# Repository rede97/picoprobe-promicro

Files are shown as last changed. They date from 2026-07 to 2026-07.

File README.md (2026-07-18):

# picoprobe-promicro

[中文版本](README_CN.md)

---

A Raspberry Pi Debug Probe expansion board based on the **RP2040 Pro Micro** core module. The circuit is fully compatible with the [official Raspberry Pi Debug Probe](https://www.raspberrypi.com/products/debug-probe/) — simply plug a RP2040 Pro Micro onto this board, flash the **official Debug Probe firmware from Raspberry Pi**, and you're ready to go. No custom firmware needed.

The RP2040 Pro Micro has onboard **Boot** and **Reset** buttons, making firmware flashing effortless: hold Boot → press Reset → release Boot, and a USB mass storage drive appears — just drag and drop the `.uf2` firmware file. No jumper wires or complicated steps required.

## Compatibility & Reliability

What's truly surprising is how well the Raspberry Pi Debug Probe works beyond its intended target. Its compatibility and reliability are **far beyond expectations**. It not only handles RP2040 chips perfectly, but also delivers rock-solid debugging and flashing for a wide range of **ARM microcontrollers and SoCs** — the full STM32 lineup, Nordic chips like the nRF52840, and virtually any Cortex-M core MCU.

Thanks to the RP2040's **PIO hardware**, the Debug Probe achieves exceptionally fast SWD transfer speeds, matching or exceeding some USB high-speed debuggers in practice. Over long debugging sessions across various target chips, it shows none of the common issues — no disconnections, no timeouts, no failed device recognition.

## Motivation

The official Raspberry Pi Debug Probe has a few shortcomings:

- It still uses a **Micro USB** connector, while USB-C has become the standard
- Flashing Picoprobe firmware onto a bare Pico often leads to **various stability issues**
- Designing a complete dedicated debugger PCB is overkill for many users
- It's essentially just an RP2040 + level-shifting circuit — the official price is steep for a fixed-function debug board

Meanwhile, open-source DAPLink solutions generally have **worse compatibility and stability** across ARM chips compared to the Raspberry Pi Debug Probe.

## Fully Open Source

This is one of the project's biggest strengths:

- **Fully open hardware**: All PCB design files (schematic, layout) are open source in KiCad format. Anyone can inspect, modify, or order their own boards
- **Firmware is fully open source**: Uses the official Raspberry Pi [debugprobe firmware](https://github.com/raspberrypi/debugprobe) directly — no proprietary or custom code. Maintained by Raspberry Pi, continuously updated, with guaranteed quality
- **No closed-source burden**: Many DAPLink debuggers on the market ship with proprietary firmware. When bugs appear, there's no one to report to and no way to upgrade or fix yourself. This solution is open source from hardware to firmware — community-driven and never obsolete

## Regarding JTAG

This project currently supports **SWD** only, not JTAG. From a practical standpoint:

- The vast majority of Cortex-M MCU debugging and flashing only requires SWD — JTAG is not necessary
- If you genuinely need JTAG along with Trace, ETM, and other advanced debugging features, a mature **J-Link** is the better choice — at that point you need a complete professional debugging toolchain, not just a protocol interface

Future firmware-level JTAG support is not out of the question (the RP2040's PIO is capable in hardware), but there are no concrete plans at this stage.

## Design Approach

Rather than designing a complete debugger from scratch, this project pairs a widely available **RP2040 Pro Micro** module with a dedicated expansion board:

- **Flexible**: Use pin headers and female header sockets to temporarily mount the Pro Micro on the board for debugging — detach and reuse it anytime
- **Permanent option**: Solder short pin headers to permanently join the Pro Micro and the board together as a dedicated, long-term debug probe
- **Ultra-low BOM cost**: Significantly cheaper than the official Debug Probe
- **Zero pressure**: No worries about damaging an expensive debugger — hack, modify, or build your own features on top

## PCB Renders

| Front | Back |
|:---:|:---:|
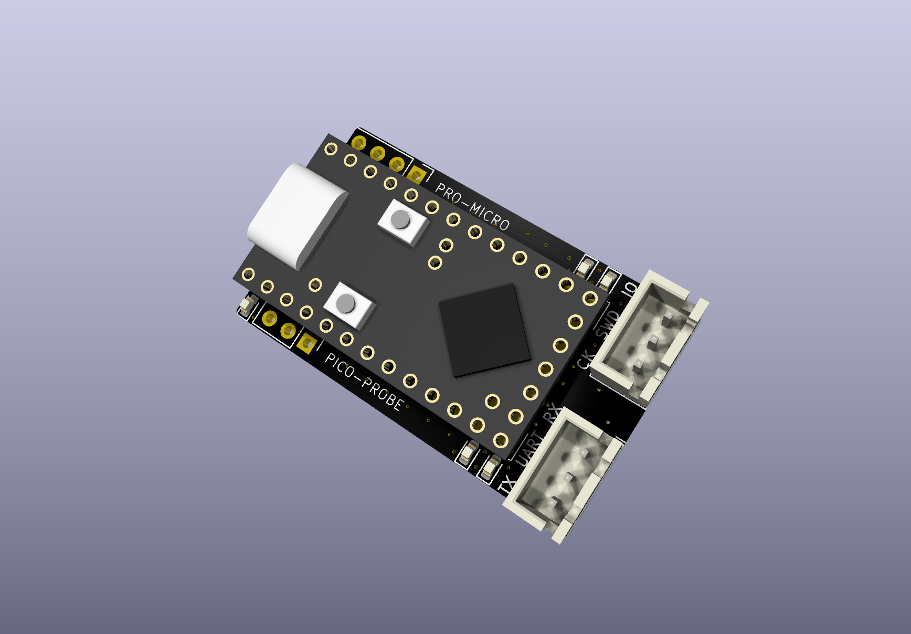
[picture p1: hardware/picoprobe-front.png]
Front
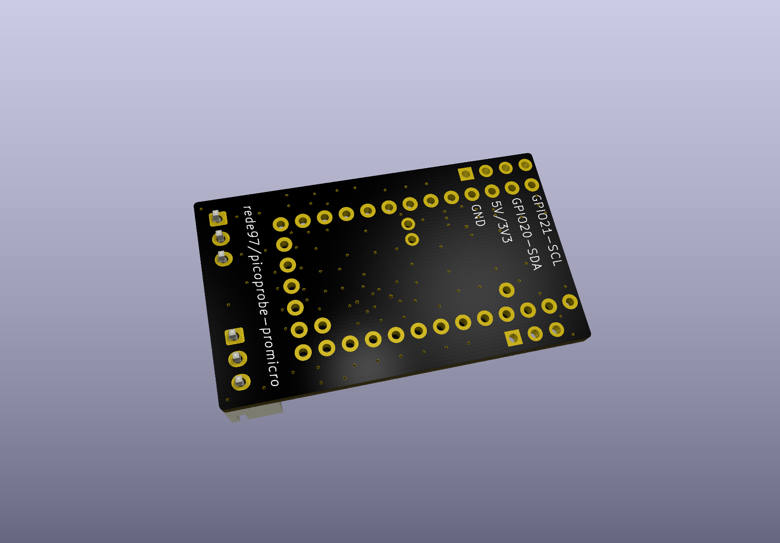
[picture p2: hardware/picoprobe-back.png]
Back
|  |  |

[Download schematic PDF](hardware/picoprobe_sch.pdf)

## Real-World Photos

This debugger works perfectly with both the **Raspberry Pi Pico 2** and the **nRF52840** — rock-solid in practice, with very fast download speeds.

### 1. Detachable socket assembly

The Pro Micro is mounted on the board via pin headers and female header sockets. Plug it in to debug; pull it off anytime and reuse the module in other projects.

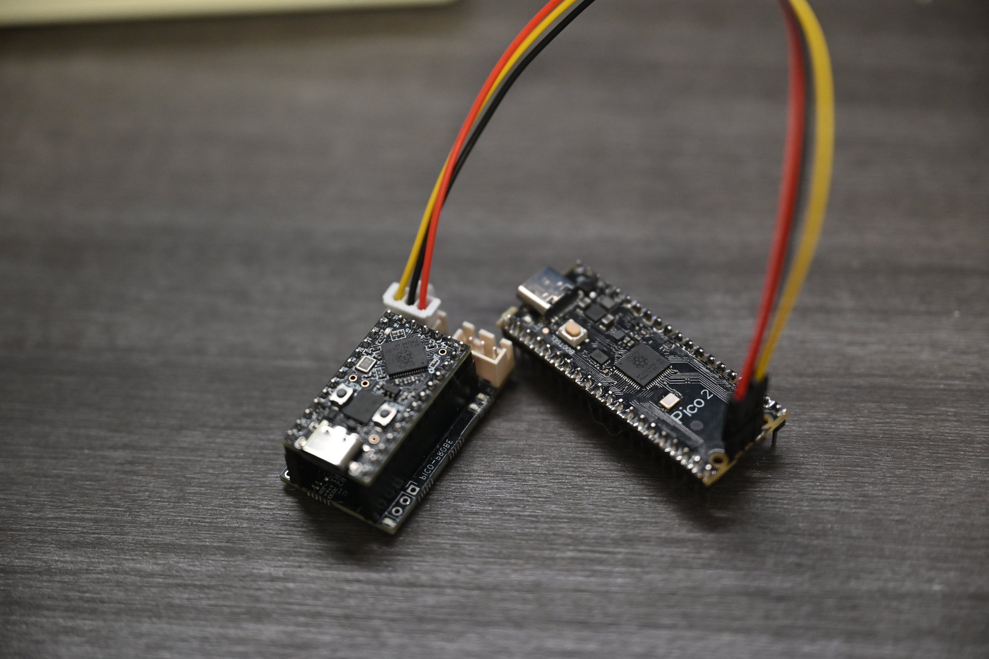
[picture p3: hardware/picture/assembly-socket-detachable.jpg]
Detachable socket assembly


### 2. Soldered as one piece

The Pro Micro is soldered directly onto the board as a single, integrated unit. This version is smaller in volume, and is otherwise **functionally identical** to the detachable version — same circuit, same performance.

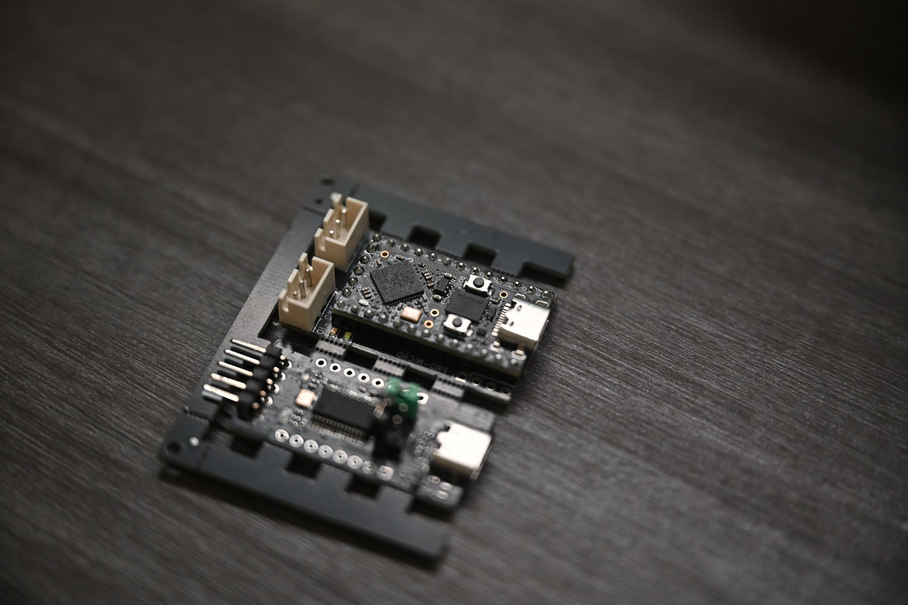
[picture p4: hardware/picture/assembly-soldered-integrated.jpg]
Soldered as one piece


### 3. Debugging an nRF52840

Debugging and flashing an nRF52840 target over SWD. Works flawlessly, with very fast download speeds.

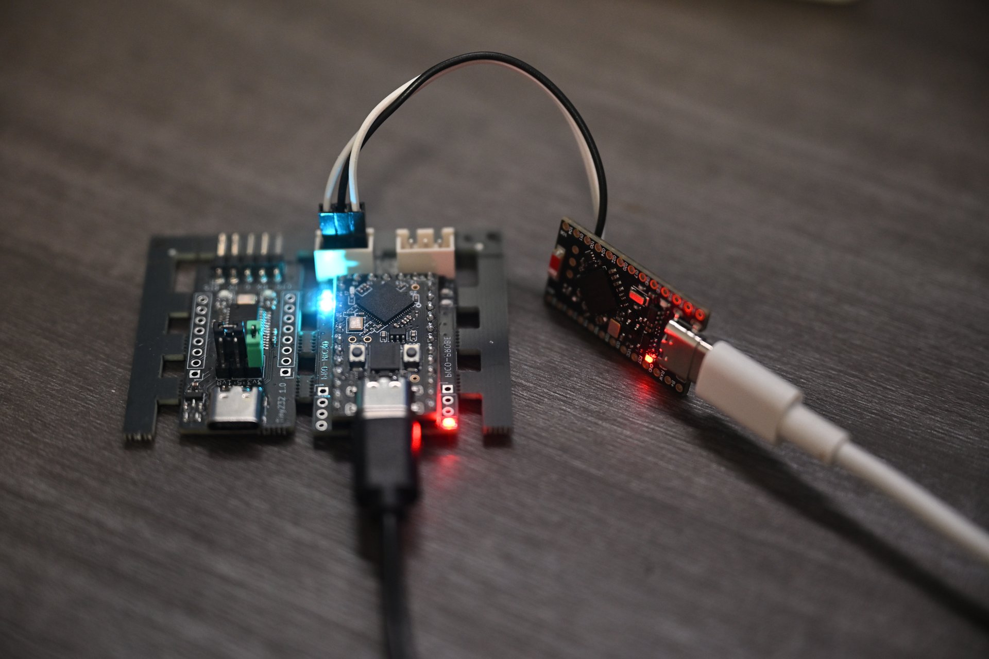
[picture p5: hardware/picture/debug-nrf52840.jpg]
Debugging an nRF52840


## Project Structure

```
├── hardware/
│   ├── picoprobe.kicad_sch      # Schematic
│   ├── picoprobe.kicad_pcb      # PCB layout
│   ├── picoprobe.kicad_pro      # KiCad project file
│   ├── picoprobe-front.png      # Front render
│   ├── picoprobe-back.png       # Back render
│   ├── picoprobe_sch.pdf        # Schematic PDF
│   ├── picture/                 # Real-world photos
│   └── kicad_pro_micro_rp2040/  # Pro Micro RP2040 footprint library (submodule)
├── README.md
└── README_CN.md
```

## Dependencies

- [kicad_pro_micro_rp2040](https://github.com/rroels/kicad_pro_micro_rp2040) — KiCad symbol and footprint library for the Pro Micro RP2040

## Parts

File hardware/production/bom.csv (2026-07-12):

Designator | Footprint | Quantity | Value | LCSC Part #
C1, C2 | 0402 | 2 | 4.7u | C23733
C3, C4 | 0402 | 2 | 0.1u | C307331
D1 | 0603 | 1 | RED LED | C2286
D2, D4 | 0603 | 2 | GREEN LED | C7496818
D3, D5 | 0603 | 2 | YELLOW LED | C965800
J1 | PinHeader_1x04_P2.54mm_Vertical | 1 | Conn_01x04_Pin
J2 | PinHeader_1x03_P2.54mm_Vertical | 1 | Conn_01x03_Pin
J3, J4 | JST_XH_B3B-XH-A_1x03_P2.50mm_Vertical | 2 | Conn_01x03_Pin
R1, R10, R9 | 0402 | 3 | 0R(NC) | C17168
R11, R12, R5, R6, R7, R8 | 0402 | 6 | 100R | C25076
R13, R14, R15, R16, R3 | 0402 | 5 | 470R | C25117
R17, R18, R19 | 0402 | 3 | 4.7k | C25900
R2 | 0402 | 1 | 0R | C17168
U1 | pro_micro_rp2040 | 1 | ~
U2, U3 | SOT-23-5 | 2 | 74AUP1G17 | C48946883

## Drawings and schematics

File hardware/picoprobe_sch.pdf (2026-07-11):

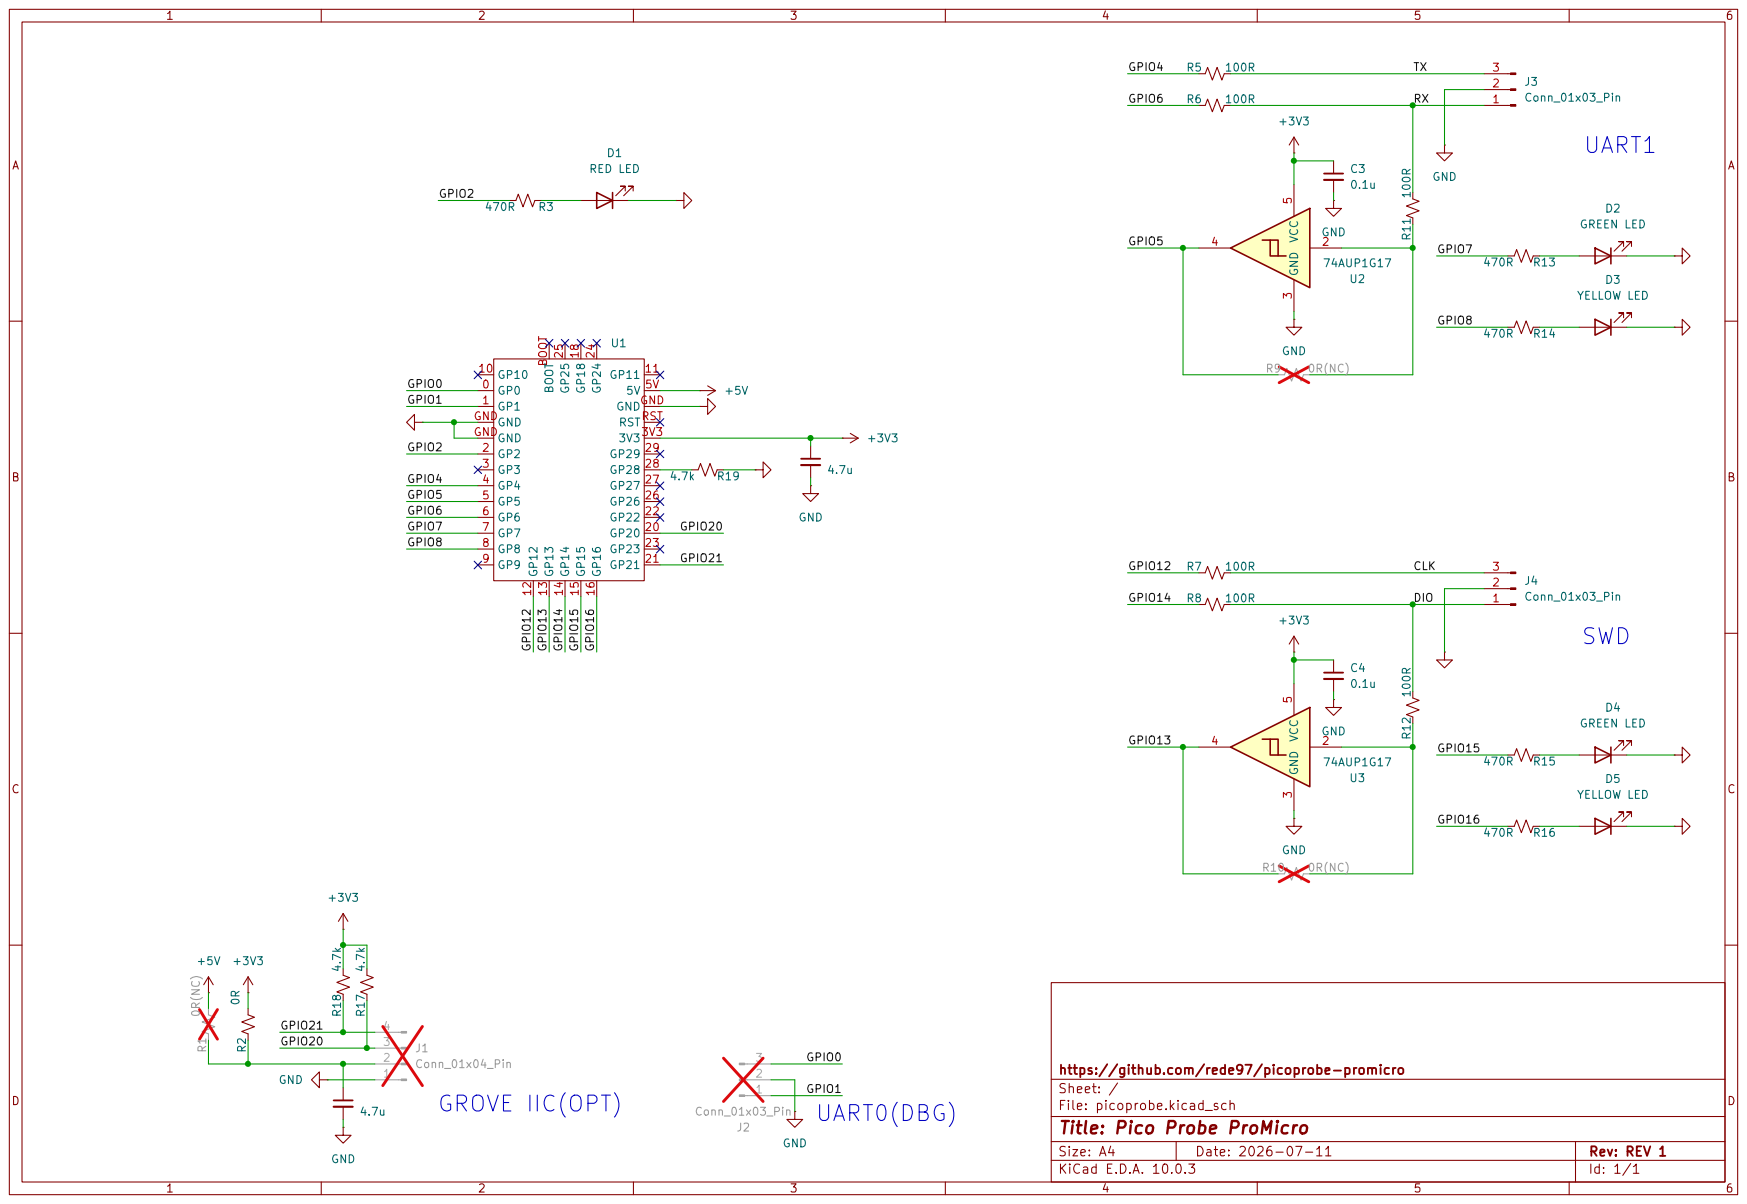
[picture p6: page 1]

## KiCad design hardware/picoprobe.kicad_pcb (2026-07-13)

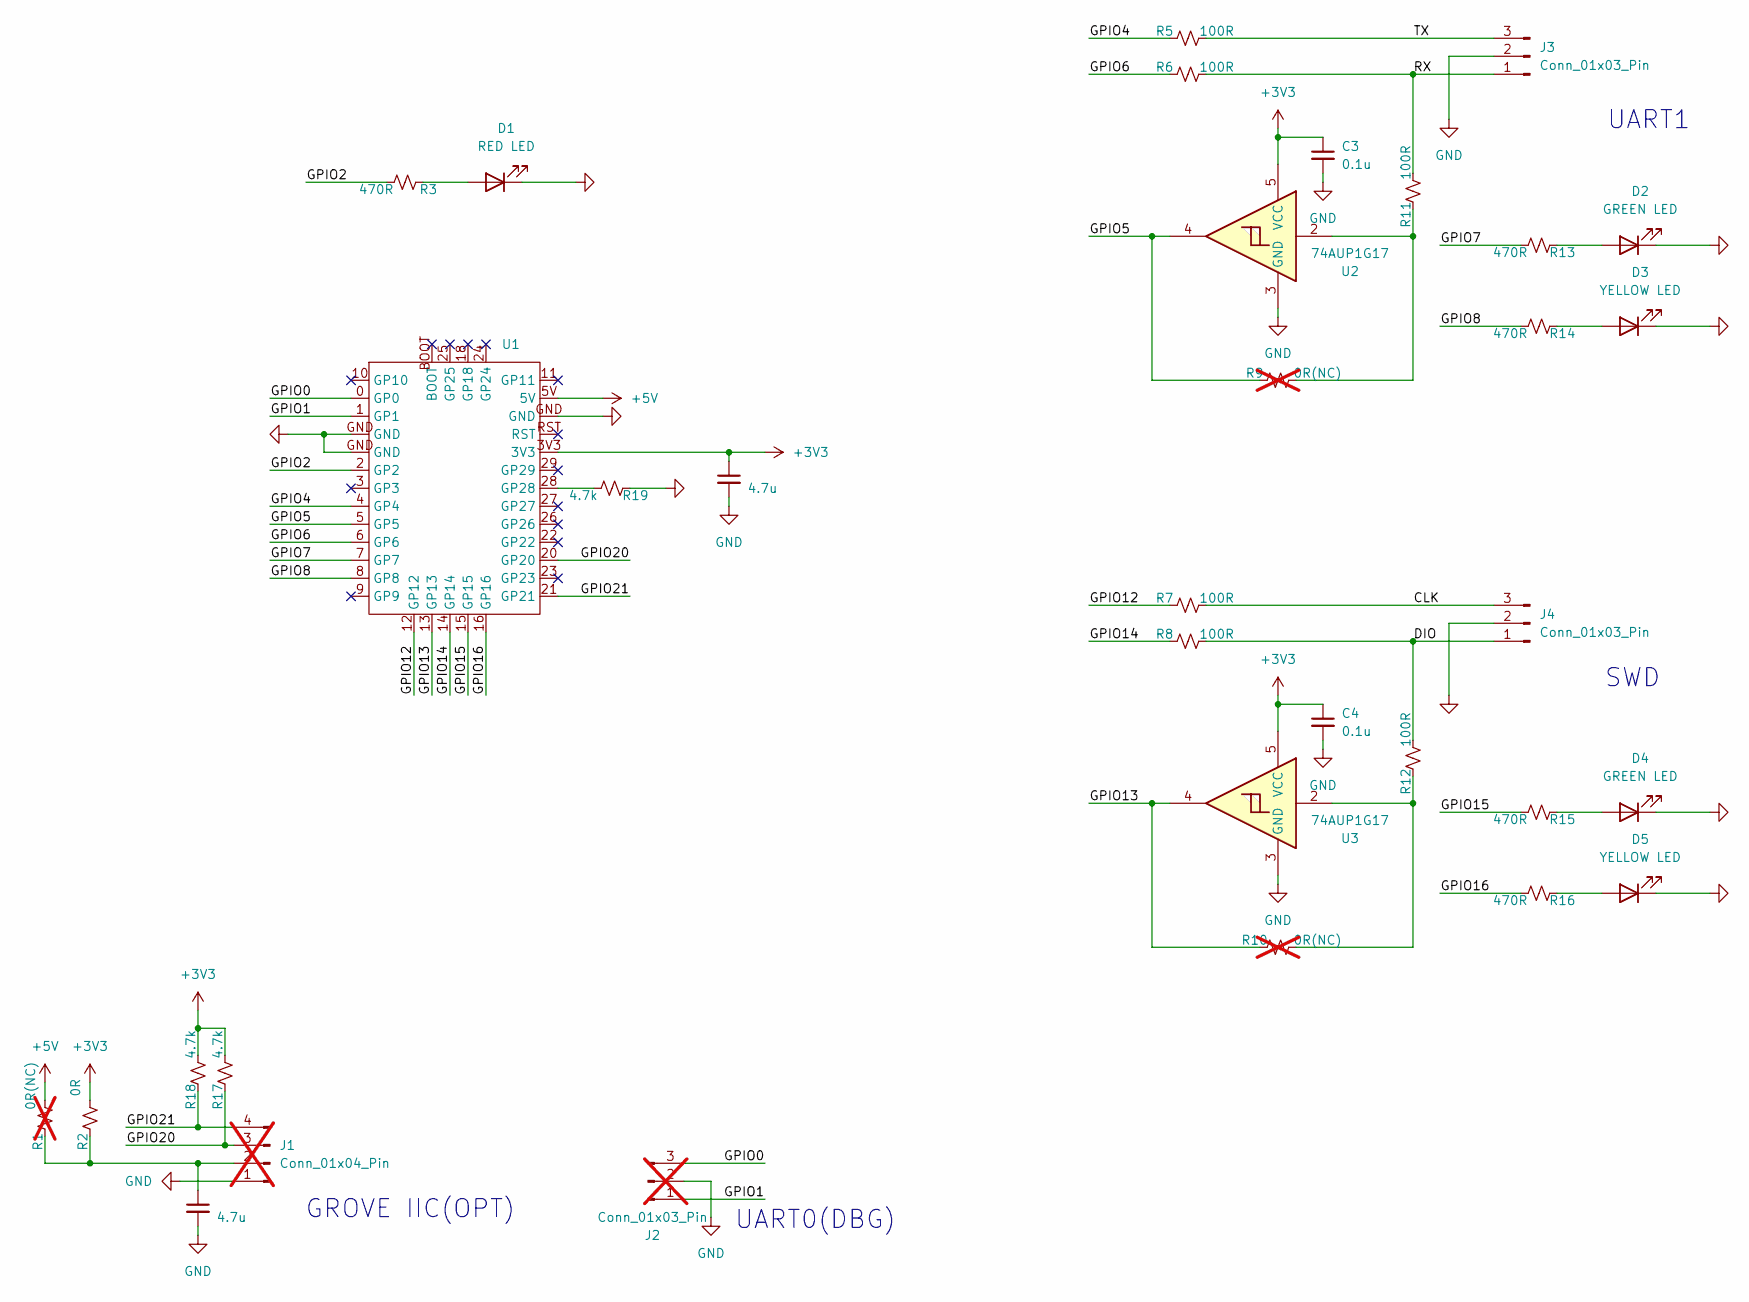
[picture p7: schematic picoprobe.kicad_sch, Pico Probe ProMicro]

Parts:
C1, C2: 4.7u; C_0402_1005Metric; LCSC Part C23733
C3, C4: 0.1u; C_0402_1005Metric; LCSC Part C307331
D1: RED LED; LED_0603_1608Metric; LCSC Part C2286
D2, D4: GREEN LED; LED_0603_1608Metric; LCSC Part C7496818
D3, D5: YELLOW LED; LED_0603_1608Metric; LCSC Part C965800
J1: Conn_01x04_Pin; PinHeader_1x04_P2.54mm_Vertical; not fitted
J2: Conn_01x03_Pin; PinHeader_1x03_P2.54mm_Vertical; not fitted
J3, J4: Conn_01x03_Pin; JST_XH_B3B-XH-A_1x03_P2.50mm_Vertical
R1: 0R(NC); R_0603_1608Metric; LCSC Part C21189; not fitted
R2: 0R; R_0603_1608Metric; LCSC Part C21189
R3, R13, R14, R15, R16: 470R; R_0402_1005Metric; LCSC Part C25117
R5, R6, R7, R8, R11, R12: 100R; R_0402_1005Metric; LCSC Part C25076
R9, R10: 0R(NC); R_0402_1005Metric; LCSC Part C17168; not fitted
R17, R18, R19: 4.7k; R_0402_1005Metric; LCSC Part C25900
U1: pro_micro_rp2040
U2, U3: 74AUP1G17; SOT-353_SC-70-5; LCSC Part C48946883

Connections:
+3V3: C2.1, C3.1, C4.1, R2.2, R17.2, R18.2, U1.3V3, U2.5 (VCC), U3.5 (VCC)
+5V: R1.2, U1.5V
/CLK: J4.3, R7.2
/DIO: J4.1, R8.2, R12.2
/GPIO0: J2.3, U1.0 (GP0)
/GPIO1: J2.1, U1.1 (GP1)
/GPIO2: R3.2, U1.2 (GP2)
/GPIO4: R5.1, U1.4 (GP4)
/GPIO5: R9.1, U1.5 (GP5), U2.4
/GPIO6: R6.1, U1.6 (GP6)
/GPIO7: R13.2, U1.7 (GP7)
/GPIO8: R14.2, U1.8 (GP8)
/GPIO12: R7.1, U1.12 (GP12)
/GPIO13: R10.1, U1.13 (GP13), U3.4
/GPIO14: R8.1, U1.14 (GP14)
/GPIO15: R15.2, U1.15 (GP15)
/GPIO16: R16.2, U1.16 (GP16)
/GPIO20: J1.3, R17.1, U1.20 (GP20)
/GPIO21: J1.4, R18.1, U1.21 (GP21)
/RX: J3.1, R6.2, R11.2
/TX: J3.3, R5.2
GND: C1.2, C2.2, C3.2, C4.2, D1.1 (K), D2.1 (K), D3.1 (K), D4.1 (K), D5.1 (K), J1.1, J2.2, J3.2, J4.2, R19.1, U1.GND, U2.3 (GND), U3.3 (GND)
unnamed: D1.2 (A), R3.1
unnamed: D2.2 (A), R13.1
unnamed: D3.2 (A), R14.1
unnamed: D4.2 (A), R15.1
unnamed: D5.2 (A), R16.1
unnamed: C1.1, J1.2, R1.1, R2.1
unnamed: R10.2, R12.1, U3.2
unnamed: R9.2, R11.1, U2.2
unnamed: R19.2, U1.28 (GP28)

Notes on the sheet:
UART0(DBG)
UART1
SWD
GROVE IIC(OPT)

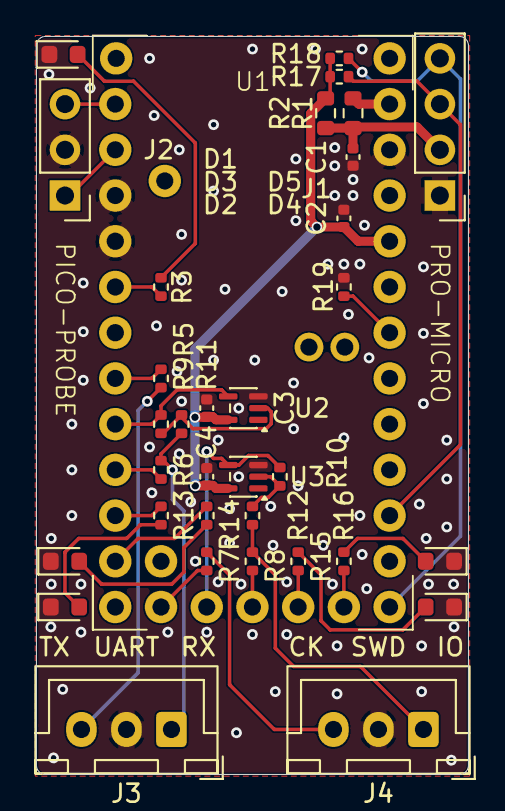
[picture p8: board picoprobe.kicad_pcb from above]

Board: 2 copper layers, 24.0 x 41.0 mm, 34 parts (0 on the bottom side), 31 nets.

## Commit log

2026-07-11 Add picoprobe debug probe expansion board design
    Fully open-source KiCad project: Raspberry Pi Debug Probe compatible
    expansion board for RP2040 Pro Micro. Includes schematic PDF, PCB
    renders, bilingual README (EN/CN), and CLAUDE.md.
    [picoprobe.kicad_pcb, picoprobe.kicad_sch]
2026-07-12 Add panelization script and gerber production files
    - Add make_smt_sample.py: 2x2 kikit panelization with frame, mousebites,
    tooling holes, and fiducials (panel < 10cm per side)
    - Add production gerber ZIP, BOM, positions, and netlist
    - Add panelized KiCad PCB files (picoprobe_panel)
    - Update .gitignore to exclude KiCad backups and fabrication toolkit
    nested output
    [bom.csv, designators.csv, picoprobe.kicad_pcb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]
2026-07-12 Move kikit panel output to hardware/smt_sample/, gitignore it
    Panel output is generated by the script and should not be committed.
    Production directory now only contains manually exported gerber/BOM/pos
    deliverables.
    [picoprobe_panel.kicad_pcb]
2026-07-12 Add picoprobe + tiny232 combined panelization script
    3 bridges (6mm tall) connect the two boards side-by-side,
    kikit adds outer SMT frame with mousebite tabs (3 horizontal + 2 vertical),
    4 tooling holes, and 8 fiducials.
2026-07-12 Reduce combined panel bridge gap from 4mm to 3mm, fix duplicate bridge lines
    Bridge height reduced from 6mm to 5mm, board-to-board gap tightened to 3mm.
    Remove duplicate add_bridge_lines() segment code that added each line twice.
2026-07-12 Add BOM conflict warning for merged panel with duplicate refs
2026-07-12 Update PCB layout: R18/R19 footprints to 0603, adjust component positions
    [picoprobe.kicad_pcb, picoprobe.kicad_sch]
2026-07-12 Minor PCB layout tweaks
    [picoprobe.kicad_pcb]
2026-07-12 Update R18/R19 LCSC part number C17168 to C21189
    [picoprobe.kicad_pcb, picoprobe.kicad_sch]
2026-07-13 Adjust F.SilkS text orientation for PICO-PROBE and PRO-MICRO labels
    Rotate from 90° to 270° and remove mirror justification to correct
    silkscreen readability on the PCB.
    [picoprobe.kicad_pcb]
2026-07-13 Update PCB front render
2026-07-13 Refine via placement and silk layer cosmetics for appearance
    [picoprobe.kicad_pcb]
2026-07-18 Add real-world photos section to README with 1080P images
    - Show socket/soldered assembly variants and nRF52840 debugging
    - Include script to resize photos to 1080P for repo size
